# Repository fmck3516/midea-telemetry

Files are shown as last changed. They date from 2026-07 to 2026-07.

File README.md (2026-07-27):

# midea-telemetry

Arduino firmware for capturing telemetry from the diagnostic port on Midea mini-splits, located on the outdoor inverter board. Midea sells a handheld inverter tester that plugs into this port. This project reproduces that tester with a cheap ESP32S3 microcontroller, so you can log the same data yourself and explore the inner workings of your unit.

The prototype has 3 capabilities:
- **Emulate the inverter tester** to capture data from the ODU (primary use case)
- **Sniff the communication** between the inverter tester and ODU (used during protocol reverse engineering)
- **Emulate the ODU** to send custom responses to the inverter tester (used to track down the meaning and encoding of individual bytes)

Example: The prototype connected to the inverter tester and diagnostic bus to sniff the communication:



Initial tests indicate that this is a robust way to extract telemetry data from my mini-splits:

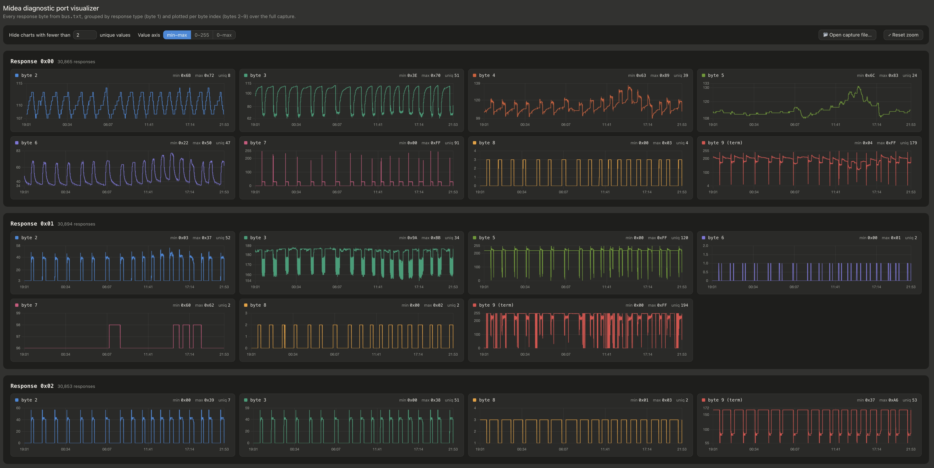
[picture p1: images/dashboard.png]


> ⚠️ **Safety.** The outdoor unit runs on mains voltage and can retain a dangerous charge after being unplugged. Only plug a connector into the diagnostic port if you know what you are doing. You are responsible for your own hardware and safety.

## Disclaimer

Midea is a trademark of Midea Group. This is an independent, unofficial hobby project and is not affiliated with, authorized, endorsed by, or sponsored by Midea. The name is used only to describe which hardware the project interoperates with. All product names and trademarks are the property of their respective owners.

## The protocol

I reverse-engineered the communication between the inverter tester and the diagnostic port and wrote it up on Medium: [Reverse Engineering Midea's ODU Diagnostic Port](https://medium.com/@florian.mckee/reverse-engineering-mideas-odu-diagnostic-port-af603e159053). The sketches in this repository are based on those findings. Start there if you want to understand the protocol.

In short: the bus is a two-wire (clock + data) 5V bus. The tester drives the clock in both directions and exchanges 80-bit frames with the ODU, LSB-first. A request starts with `0xAA`, a response with `0x55`; the second byte selects one of seven response types, and the last byte is a checksum that makes all ten bytes sum to zero modulo 256.

## Hardware

The only thing you need to connect an ESP32 to the diagnostic port is a level shifter. The 5V bus lines (CLK, DAT) are level-shifted to 3V3; the ODU supplies the 5V reference and the XIAO supplies the 3V3 reference. All sketches expect the clock line on **D2** and the data line on **D1** (see the `PIN_CLK` / `PIN_DAT` defines at the top of each sketch).

> ⚠️ **Use a USB isolator.** The diagnostic port's ground is not referenced to earth. Whenever you connect the ESP32 to a computer over USB while it's plugged into the ODU (e.g. to flash or read the serial monitor), go through a USB isolator so the floating bus ground isn't tied to your earthed computer.

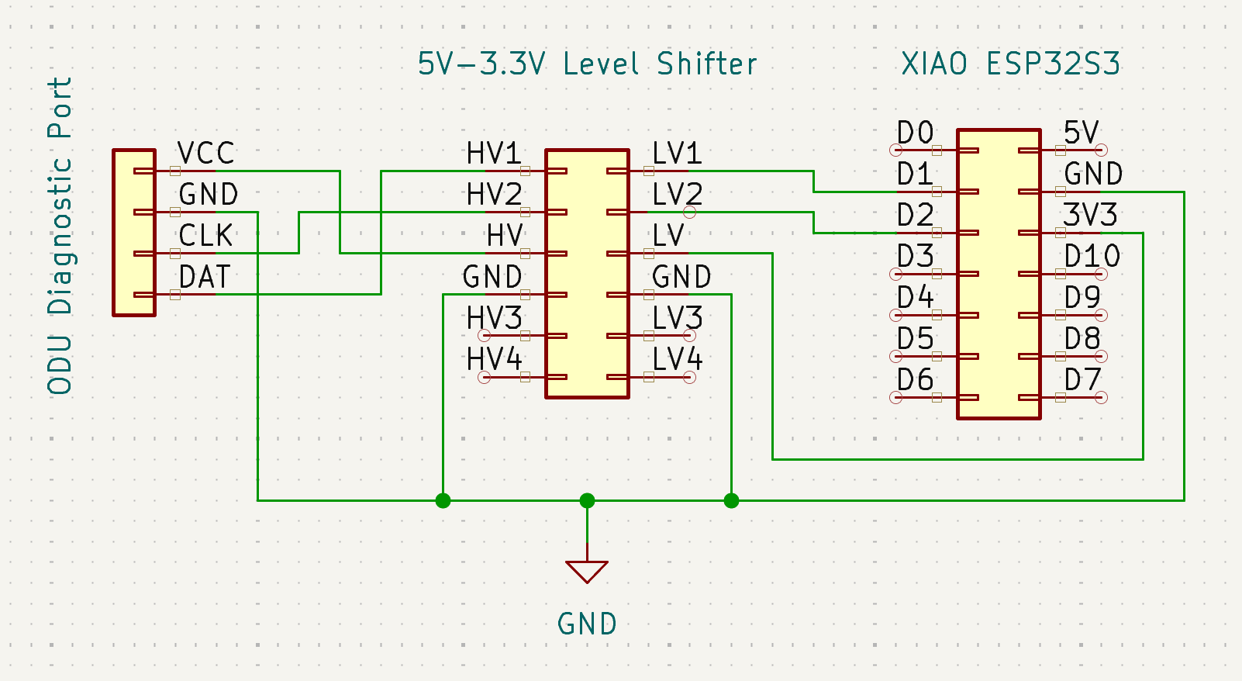
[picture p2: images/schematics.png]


BOM:
- [3.3V-5V Level Shifter](https://www.amazon.com/dp/B07F7W91LC)
- [XIAO ESP32S3](https://www.amazon.com/dp/B0BYSB66S5)

The assembled prototype:



An **adapter PCB** for this — a bare carrier board you solder the two connectors, the level shifter and the XIAO into — lives in the companion repo: [midea-telemetry-esphome/pcb](https://github.com/fmck3516/midea-telemetry-esphome/tree/main/pcb) (KiCad project, schematic, and orderable gerbers). Note it is **untested** — designed and rule-checked, but not yet fabricated.

> ⚠️ Only the ODU side connects to your mini-split, and only through the low-voltage diagnostic port. Re-read the safety note above before plugging anything into the outdoor unit.

## Sketches

| Sketch | Role on the bus | Use it to... |
|---|---|---|
| [inverter-tester-emulator](arduino/inverter-tester-emulator/inverter-tester-emulator.ino) | drives the bus like the tester | capture telemetry without owning the tester |
| [bus-sniffer](arduino/bus-sniffer/bus-sniffer.ino) | passive listener | reverse-engineer tester ↔ ODU traffic |
| [odu-emulator](arduino/odu-emulator/odu-emulator.ino) | answers like the ODU | map response bytes to tester display fields |

### `inverter-tester-emulator.ino`

Emulates Midea's inverter tester: it **drives** the bus, sending diagnostic requests and logging the ODU's responses. This lets you capture telemetry **without owning the inverter tester**.

The set of request messages to send is defined in the `requests` table in `loop()`. Edit it to send different requests. Each request/response pair is printed to serial:

```
req=0xAA000000000000000056, res=0xFFFFFFFFFFFFFFFFFFFF, status=NO_RESPONSE_FROM_ODU
req=0xAA000000000000000056, res=0xFFFFFFFFFFFFFFFFFFFF, status=NO_RESPONSE_FROM_ODU
req=0xAA000000000000000056, res=0x55006D457671401F03B0, status=OK
req=0xAA010000000000000055, res=0x550128A7B3E8006002DE, status=OK
req=0xAA0200000000FF000055, res=0x55022C2A000000000152, status=OK
req=0xAA030000000000000053, res=0x55030000160EA20000E2, status=OK
req=0xAA000000000000000056, res=0x550400000000002C2C4F, status=OK
req=0xAA010000000000000055, res=0x55054F00000000000057, status=OK
req=0xAA0200000000FF000055, res=0x550600000000000000A5, status=OK
...
req=0xAA030000000000000053, res=0x55030000160BA00000E3, status=CHECKSUM_ERROR
...
```

### `bus-sniffer.ino`

Passively **listens** on the bus while the **inverter tester is plugged in**, decoding the request/response cycles between the tester and the ODU. Useful for reverse-engineering the protocol. Each request/response pair is printed to serial in the same format as above.

When a request or response fails to decode, you'll see a line like:
```
req=                      , res=                      , status=INCOMPLETE
```

Note: I initially used an ESP32C3 and regularly encountered messages that don't decode fully — some bits are lost when `loop()` isn't called fast enough. There are ways around this, but I prefer to keep the sketch simple, and I can still capture enough data for analysis (even if it takes a couple of tries). Switching to an ESP32S3 has resolved those issues for me.

### `odu-emulator.ino`

Emulates the **ODU**: it waits for the inverter tester to clock out a request, then answers with a configurable response frame. By changing individual response bytes and watching what changes on the tester's display, you can map each byte to a display field and work out the conversion between raw byte and displayed value.

The seven response payloads (bytes 0–8 of each frame) are defined in the `responsePayloads` table at the top of the sketch. The checksum (byte 9) is always generated automatically, so any payload byte can be changed freely.

Payloads can also be changed **at runtime over USB serial** — no reflashing between experiments:

```
show                     print all response frames (checksum included)
set <slot> <18 hex>      replace bytes 0-8 of a frame, e.g. set 2 55022C2A0000000001
poke <slot> <byte> <value> change a single byte (0-8); value is decimal,
                         or hex with a 0x prefix, e.g. poke 2 2 0x2B
```

A typical session — bump one byte, watch the tester display:

```
2: 0x55022C2A000000000152
> poke 2 2 0x2B
2: 0x55022B2A000000000153
```

Tip: the two emulator sketches are exact counterparts, so you can bench-test them against each other with two boards (clock-to-clock, data-to-data, ground-to-ground) before connecting real hardware — no external pull-ups needed.

## ESPHome component (Home Assistant)

[midea-telemetry-esphome](https://github.com/fmck3516/midea-telemetry-esphome) is an ESPHome external component that emulates the inverter tester and exposes all currently known telemetry fields (temperatures, compressor frequencies, fan speed, EEV steps, voltage, current, mode, set-point) as Home Assistant sensors. Same hardware as the sketches — see its README for a full example configuration.

```yaml
external_components:
  - source: github://fmck3516/midea-telemetry-esphome
    components: [midea_telemetry]

midea_telemetry:
  clk_pin: GPIO3   # D2 on the XIAO ESP32S3
  dat_pin: GPIO2   # D1

sensor:
  - platform: midea_telemetry
    outdoor_coil_temperature:
      name: Outdoor coil temperature
    compressor_frequency_actual:
      name: Compressor frequency
    # ... see the midea-telemetry-esphome README for all 13 sensors
```

## Dashboard

[dashboard/index.html](dashboard/index.html) is a self-contained, browser-based visualizer for captured telemetry — no build step, just open it in a browser. Pick a capture file and it plots every response byte (bytes 2–9) over time, grouped by response type (byte 1), with synced zoom/pan across charts. Bytes that never change are hidden automatically. By default it shows the twelve decoded fields ("known bytes" — temperatures, frequencies, fan speed, EEV steps, voltage, current), converted with the formulas from the article; an "all bytes" toggle switches to the raw per-byte charts.

It expects capture files with one `req=..., res=..., status=...` line per cycle, prefixed with a Unix timestamp — see [data/bus.txt](data/bus.txt) for an example. A capture like that can be recorded straight from the serial port:

```bash
cat /dev/ttyACM0 | while IFS= read -r line; do echo "$(date +%s) $line"; done >> data/$(date +%F).bus.txt
```

## Building & flashing

1. Install the [Arduino IDE](https://www.arduino.cc/en/software) and the **esp32 by Espressif Systems** boards package (3.x) via the Boards Manager.
2. Open the sketch you want.
3. Select your board (e.g., XIAO_ESP32S3) and serial port, then upload.
4. Open the **Serial Monitor** to view the captured telemetry. The sketches print over the native USB port (`HWCDCSerial`), so any baud rate works.

## Status

Early / experimental. The protocol is still being reverse-engineered, and the meaning of individual bytes is not yet fully documented.

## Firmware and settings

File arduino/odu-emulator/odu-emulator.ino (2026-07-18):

#include <Arduino.h>

#define PIN_CLK D2
#define PIN_DAT D1

#define MESSAGE_WIDTH 80
#define FRAME_BYTES (MESSAGE_WIDTH / 8)
#define NUM_RESPONSES 7

// Bytes 0-8 of each response frame, indexed by the request's second byte
// (0xAA 0x00 .. -> slot 0, 0xAA 0x01 .. -> slot 1, ...). Byte 9, the
// checksum, is generated automatically whenever a frame is sent, so any
// payload byte can be changed freely. Edit the defaults here, or change them
// at runtime over USB serial without reflashing (type "help" in the monitor).
uint8_t responsePayloads[NUM_RESPONSES][FRAME_BYTES - 1] = {
  {0x55, 0x00, 0x6D, 0x45, 0x76, 0x71, 0x40, 0x1F, 0x03},
  {0x55, 0x01, 0x28, 0xA7, 0xB3, 0xE8, 0x00, 0x60, 0x02},
  {0x55, 0x02, 0x2C, 0x2A, 0x00, 0x00, 0x00, 0x00, 0x01},
  {0x55, 0x03, 0x00, 0x00, 0x16, 0x0E, 0xA2, 0x00, 0x00},
  {0x55, 0x04, 0x00, 0x00, 0x00, 0x00, 0x00, 0x2C, 0x2C},
  {0x55, 0x05, 0x4F, 0x00, 0x00, 0x00, 0x00, 0x00, 0x00},
  {0x55, 0x06, 0x00, 0x00, 0x00, 0x00, 0x00, 0x00, 0x00},
};

// A request can arrive as 80 bits, or 84 with the 4-bit handshake prefix.
uint32_t requestBits[84];
uint32_t bitCount = 0;
uint32_t lastEdge = 0;
int clockLevel;

char commandLine[64];
size_t commandLength = 0;

// Releasing to INPUT_PULLUP (instead of plain INPUT) means the sketch also
// works on the bench against inverter-tester-emulator without the bus or
// external pull-up resistors.
static inline void setLine(uint8_t pin, uint8_t level) {
  if (level)
    pinMode(pin, INPUT_PULLUP);  // release - pull-up brings it high
  else {
    pinMode(pin, OUTPUT);
    digitalWrite(pin, LOW);
  }
}

// The last byte makes all ten bytes of a frame sum to zero modulo 256.
uint8_t checksumFor(const uint8_t *payload) {
  uint8_t sum = 0;
  for (size_t i = 0; i < FRAME_BYTES - 1; i++) {
    sum += payload[i];
  }
  return (uint8_t)(0 - sum);
}

// Assembles a byte from the wire bits LSB-first, matching how the ODU
// interprets a frame (the first bit clocked is bit 0).
static uint8_t byteFromBits(const uint32_t *bits, size_t byteIndex) {
  uint8_t b = 0;
  for (int bitIndex = 0; bitIndex < 8; bitIndex++) {
    if (bits[byteIndex * 8 + bitIndex]) b |= 1 << bitIndex;
  }
  return b;
}

bool checksumValid(const uint32_t *bits) {
  uint8_t sum = 0;
  for (size_t byteIndex = 0; byteIndex < FRAME_BYTES; byteIndex++) {
    sum += byteFromBits(bits, byteIndex);
  }
  return sum == 0;
}

void printBitsAsHex(const uint32_t *bits) {
  for (size_t byteIndex = 0; byteIndex < FRAME_BYTES; byteIndex++) {
    uint8_t b = byteFromBits(bits, byteIndex);
    if (b < 0x10) HWCDCSerial.print('0');  // keep the leading zero
    HWCDCSerial.print(b, HEX);
  }
}

void printBytesAsHex(const uint8_t *bytes, size_t count) {
  for (size_t i = 0; i < count; i++) {
    if (bytes[i] < 0x10) HWCDCSerial.print('0');  // keep the leading zero
    HWCDCSerial.print(bytes[i], HEX);
  }
}

static bool waitForClock(uint8_t level, uint32_t timeoutMs) {
  uint32_t start = millis();
  while (digitalRead(PIN_CLK) != level) {
    if (millis() - start > timeoutMs) return false;
  }
  return true;
}

// Drives one response frame onto the bus. The tester keeps driving the
// clock: it raises CLK, samples DAT ~1ms later, then drives CLK low again.
// So each bit is placed on DAT while CLK is low and advanced on the falling
// edge. The full frame (payload + fresh checksum) is copied to frameOut for
// logging. Returns false if the tester stops clocking mid-frame.
bool sendResponse(const uint8_t *payload, uint8_t *frameOut) {
  memcpy(frameOut, payload, FRAME_BYTES - 1);
  frameOut[FRAME_BYTES - 1] = checksumFor(payload);
  bool ok = true;
  for (uint32_t i = 0; i < MESSAGE_WIDTH && ok; i++) {
    setLine(PIN_DAT, (frameOut[i / 8] >> (i % 8)) & 1);  // LSB-first
    ok = waitForClock(HIGH, 2000) && waitForClock(LOW, 2000);
  }
  pinMode(PIN_DAT, INPUT_PULLUP);  // release the data line
  return ok;
}

void handleRequest(const uint32_t *bits) {
  uint8_t header = byteFromBits(bits, 0);
  uint8_t index = byteFromBits(bits, 1);
  uint8_t frame[FRAME_BYTES];
  bool responded = false;
  const char *status;

  if (header != 0xAA) {
    status = "NOT_A_REQUEST";
  } else if (!checksumValid(bits)) {
    status = "CHECKSUM_ERROR";
  } else if (index >= NUM_RESPONSES) {
    status = "NO_RESPONSE_CONFIGURED";
  } else {
    // The tester starts clocking the response ~60ms after the request, so
    // respond first and log afterwards.
    responded = sendResponse(responsePayloads[index], frame);
    status = responded ? "OK" : "TIMEOUT";
  }

  HWCDCSerial.print("req=0x");
  printBitsAsHex(bits);
  HWCDCSerial.print(", res=0x");
  if (responded) {
    printBytesAsHex(frame, FRAME_BYTES);
  } else {
    HWCDCSerial.print("--------------------");
  }
  HWCDCSerial.print(", status=");
  HWCDCSerial.println(status);
}

void printFrame(size_t slot) {
  HWCDCSerial.print(slot);
  HWCDCSerial.print(": 0x");
  printBytesAsHex(responsePayloads[slot], FRAME_BYTES - 1);
  uint8_t checksum = checksumFor(responsePayloads[slot]);
  printBytesAsHex(&checksum, 1);
  HWCDCSerial.println();
}

void printAllFrames() {
  for (size_t slot = 0; slot < NUM_RESPONSES; slot++) {
    printFrame(slot);
  }
}

void printHelp() {
  HWCDCSerial.println("commands:");
  HWCDCSerial.println("  show                    print all response frames (checksum included)");
  HWCDCSerial.println("  set <slot> <18 hex>     replace bytes 0-8, e.g. set 2 55022C2A0000000001");
  HWCDCSerial.println("                          (20 hex chars also accepted; the checksum is ignored)");
  HWCDCSerial.println("  poke <slot> <byte> <value>  change one byte (0-8); value is decimal,");
  HWCDCSerial.println("                          or hex with 0x prefix, e.g. poke 2 2 0x2B");
}

static int hexNibble(char c) {
  if (c >= '0' && c <= '9') return c - '0';
  if (c >= 'a' && c <= 'f') return c - 'a' + 10;
  if (c >= 'A' && c <= 'F') return c - 'A' + 10;
  return -1;
}

static bool parseHexBytes(const char *s, uint8_t *out, size_t count) {
  for (size_t i = 0; i < count; i++) {
    int hi = hexNibble(s[2 * i]);
    int lo = hexNibble(s[2 * i + 1]);
    if (hi < 0 || lo < 0) return false;
    out[i] = (hi << 4) | lo;
  }
  return true;
}

// Parses a byte value: hex with a 0x prefix (0x2B), decimal otherwise (43).
// Returns -1 if the value is malformed or out of range.
static int parseByteValue(const char *s) {
  bool isHex = s[0] == '0' && (s[1] == 'x' || s[1] == 'X');
  const char *digits = isHex ? s + 2 : s;
  char *end;
  long value = strtol(digits, &end, isHex ? 16 : 10);
  if (end == digits || *end != 0 || value < 0 || value > 255) return -1;
  return (int)value;
}

void handleCommand(char *line) {
  char *verb = strtok(line, " ");
  if (verb == NULL) return;

  if (strcmp(verb, "show") == 0) {
    printAllFrames();
    return;
  }

  if (strcmp(verb, "set") == 0) {
    char *slotArg = strtok(NULL, " ");
    char *hexArg = strtok(NULL, " ");
    if (slotArg == NULL || hexArg == NULL) {
      HWCDCSerial.println("err: usage: set <slot> <18 hex chars>");
      return;
    }
    int slot = atoi(slotArg);
    size_t hexLength = strlen(hexArg);
    uint8_t payload[FRAME_BYTES - 1];
    if (slot < 0 || slot >= NUM_RESPONSES) {
      HWCDCSerial.println("err: slot must be 0-6");
    } else if ((hexLength != 18 && hexLength != 20) || !parseHexBytes(hexArg, payload, FRAME_BYTES - 1)) {
      HWCDCSerial.println("err: expected 18 hex chars (bytes 0-8)");
    } else {
      memcpy(responsePayloads[slot], payload, FRAME_BYTES - 1);
      printFrame(slot);
    }
    return;
  }

  if (strcmp(verb, "poke") == 0) {
    char *slotArg = strtok(NULL, " ");
    char *posArg = strtok(NULL, " ");
    char *valueArg = strtok(NULL, " ");
    if (slotArg == NULL || posArg == NULL || valueArg == NULL) {
      HWCDCSerial.println("err: usage: poke <slot> <byte 0-8> <value>");
      return;
    }
    int slot = atoi(slotArg);
    int pos = atoi(posArg);
    int value = parseByteValue(valueArg);
    if (slot < 0 || slot >= NUM_RESPONSES) {
      HWCDCSerial.println("err: slot must be 0-6");
    } else if (pos < 0 || pos > FRAME_BYTES - 2) {
      HWCDCSerial.println("err: byte position must be 0-8");
    } else if (value < 0) {
      HWCDCSerial.println("err: value must be 0-255 (decimal) or 0x00-0xFF (hex)");
    } else {
      responsePayloads[slot][pos] = (uint8_t)value;
      printFrame(slot);
    }
    return;
  }

  printHelp();
}

void pollSerial() {
  while (HWCDCSerial.available()) {
    char c = HWCDCSerial.read();
    if (c == '\r') continue;
    if (c == '\n') {
      commandLine[commandLength] = 0;
      commandLength = 0;
      handleCommand(commandLine);
    } else if (commandLength < sizeof(commandLine) - 1) {
      commandLine[commandLength++] = c;
    }
  }
}

void setup() {
  HWCDCSerial.begin();
  pinMode(PIN_CLK, INPUT_PULLUP);
  pinMode(PIN_DAT, INPUT_PULLUP);
  delay(2000);
  clockLevel = digitalRead(PIN_CLK);
  lastEdge = millis();
  HWCDCSerial.println("ODU emulator ready, current response frames:");
  printAllFrames();
  printHelp();
}

void loop() {

  pollSerial();

  int newClockLevel = digitalRead(PIN_CLK);

  if (newClockLevel != clockLevel) {

    clockLevel = newClockLevel;
    lastEdge = millis();

    // The tester puts the data bit on the line before driving the clock low,
    // so the rising edge is the middle of the bit - the safest place to sample.
    if (newClockLevel == HIGH && bitCount < sizeof(requestBits) / sizeof(requestBits[0])) {
      requestBits[bitCount++] = digitalRead(PIN_DAT);
    }

  } else if (bitCount > 0 && millis() - lastEdge > 10) {

    // No clock edge for 10ms -> the message is complete. The tester waits
    // ~60ms before clocking the response, so there is time to get ready.
    if (bitCount == 80) {

      handleRequest(requestBits);

    } else if (bitCount == 84) {

      // 4 zero bits from the handshake + 80-bit wide message
      handleRequest(requestBits + 4);

    } else if (bitCount > 4) {

      HWCDCSerial.println("req=                      , res=                      , status=INCOMPLETE");

    }
    // 4 bits or fewer: handshake fragments or noise -> discard silently

    bitCount = 0;
    clockLevel = digitalRead(PIN_CLK);
    lastEdge = millis();

  }

}

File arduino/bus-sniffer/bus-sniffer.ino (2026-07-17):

#include <Arduino.h>

#define PIN_CLK D2
#define PIN_DAT D1

#define MESSAGE_WIDTH 80

uint32_t dataDuringClockChange[84];
uint32_t dataDuringClockChangePointer = 0;
uint32_t clockLevel;
uint32_t lstClockChange;
uint32_t clockChanges = 0;

// A request/response cycle is two consecutive messages on the bus: the tester
// sends the request, then the ODU clocks back its response. We buffer the
// request until the response arrives, then print them together.
uint32_t request[80];

void setup() {
  HWCDCSerial.begin();
  pinMode(PIN_CLK, INPUT_PULLUP);
  pinMode(PIN_DAT, INPUT_PULLUP);
  delay(2000);
  clockLevel = digitalRead(PIN_CLK);
  lstClockChange = millis();
}

bool allHigh(uint32_t *bits) {
  for (uint32_t i = 0; i < MESSAGE_WIDTH; i++) {
    if (bits[i] == 0) {
      return false;
    }
  }
  return true;
}

// Assembles a byte from the wire bits LSB-first, matching how the ODU
// interprets a frame (the first bit clocked is bit 0).
static uint8_t byteFromBits(const uint32_t *bits, uint32_t byteIndex) {
  uint8_t b = 0;
  for (uint32_t bitIndex = 0; bitIndex < 8; bitIndex++) {
    if (bits[byteIndex * 8 + bitIndex]) b |= 1 << bitIndex;
  }
  return b;
}

// The last byte is a checksum: with bytes read LSB-first the way the ODU does,
// a frame is valid exactly when payload and checksum sum to zero modulo 256.
bool checksumValid(uint32_t *bits) {
  uint8_t sum = 0;
  for (size_t byteIndex = 0; byteIndex < MESSAGE_WIDTH / 8; byteIndex++) {
    sum += byteFromBits(bits, byteIndex);
  }
  return sum == 0;
}

void printHex(uint32_t *message) {
  HWCDCSerial.print("0x");
  for (uint32_t byteIndex = 0; byteIndex < 80 / 8; byteIndex++) {
    uint8_t b = byteFromBits(message, byteIndex);
    if (b < 0x10) HWCDCSerial.print('0');  // keep the leading zero
    HWCDCSerial.print(b, HEX);
  }
}

// Read LSB-first, a request opens with the header byte 0xAA, a response with
// 0x55. Rebuild the first byte from its bits and check for the request header.
boolean isRequest(uint32_t *message) {
  return byteFromBits(message, 0) == 0xAA;
}

void handleMessage(uint32_t *message, uint32_t count) {
  
  if (isRequest(message)) {
    for (uint32_t i = 0; i < count; i++) {
      request[i] = message[count == 84 ? 4 : 0 + i];
    }
    return;
  }
  // second message of a cycle -> the ODU's response; emit the pair
  HWCDCSerial.print("req=");
  printHex(request);
  HWCDCSerial.print(", res=");
  printHex(message);
  if (allHigh(message)) {
      HWCDCSerial.println(", status=NO_RESPONSE_FROM_ODU");
    } else if ( ! checksumValid(request) || ! checksumValid(message)) {
      HWCDCSerial.println(", status=CHECKSUM_ERROR");
    } else {
      HWCDCSerial.println(", status=OK");
    }
}

void loop() {
  
  uint32_t newClockLevel = digitalRead(PIN_CLK);
  
  if (clockLevel != newClockLevel) {
  
    lstClockChange = millis();
    clockLevel = newClockLevel;
    
    if (clockChanges % 2 == 1) {

      // Capture the level of the data line in the middle of a clock cycle
      // (e.g., every other time the level changes from HIGH to LOW or vice versa):
      //
      //                 ↓         ↓
      //  ----------|    |----|    |----|   
      //            |    |    |    |    |    
      //            |----|    |----|    |----
      //      
      dataDuringClockChange[dataDuringClockChangePointer] = digitalRead(PIN_DAT);
      dataDuringClockChangePointer++;

    }
    
    clockChanges++;

    // A clock burst changes the level of the clock pin every ms. If there is no change since 10ms, 
    // we've either seen a completed message or an irrelevant change of the clock signal
  
  } else if ((millis() - lstClockChange > 10) && clockChanges > 0) {

    if (clockChanges == 1) {

      // noise -> discard

    } else if (clockChanges == 169) {

      // 4 zero bits from the handshake + 80-bit wide message
      handleMessage(dataDuringClockChange, 84);

    } else if (clockChanges == 161) {

      // regular 80-bit message
      handleMessage(dataDuringClockChange, 80);

    } else {
      
      // incomplete message
      HWCDCSerial.println("req=                      , res=                      , status=INCOMPLETE");

    }

    clockChanges = 0;
    dataDuringClockChangePointer = 0;

  }

}

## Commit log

2026-07-16 added schematic
    [schematics.kicad_pcb, schematics.kicad_sch]
2026-07-17 more work on schematics
2026-07-17 switch to HWCDCSerial
    [schematics.kicad_sch]
2026-07-25 moved schematics to midea-telemetry-esphome repo
    [schematics.kicad_pcb, schematics.kicad_sch]
